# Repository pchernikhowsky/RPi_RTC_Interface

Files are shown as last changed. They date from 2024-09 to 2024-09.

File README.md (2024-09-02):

# Raspberry Pi RTC / Interface Board

## Description

A Raspberry Pi HAT-style interface board that includes:
* [DS3231](https://www.analog.com/en/products/ds3231.html) highly accurate real-time clock (RTC) with replaceable battery backup
* [DS18B20](https://www.analog.com/en/products/ds18b20.html) precision temperature sensor
* 3-pin header terminal for access to the Pi serial console (`/dev/ttyS0` a.k.a. `/dev/serial0`) connection
* Screw terminals for connecting [I2C](https://en.wikipedia.org/wiki/I%C2%B2C) devices (such as displays, sensors, D/A and A/D converters, etc.)
* Screw terminals for connecting [1-Wire](https://en.wikipedia.org/wiki/1-Wire) devices (such as additional DS18B20 sensors and other 1-Wire compatible devices)
<p align="center">
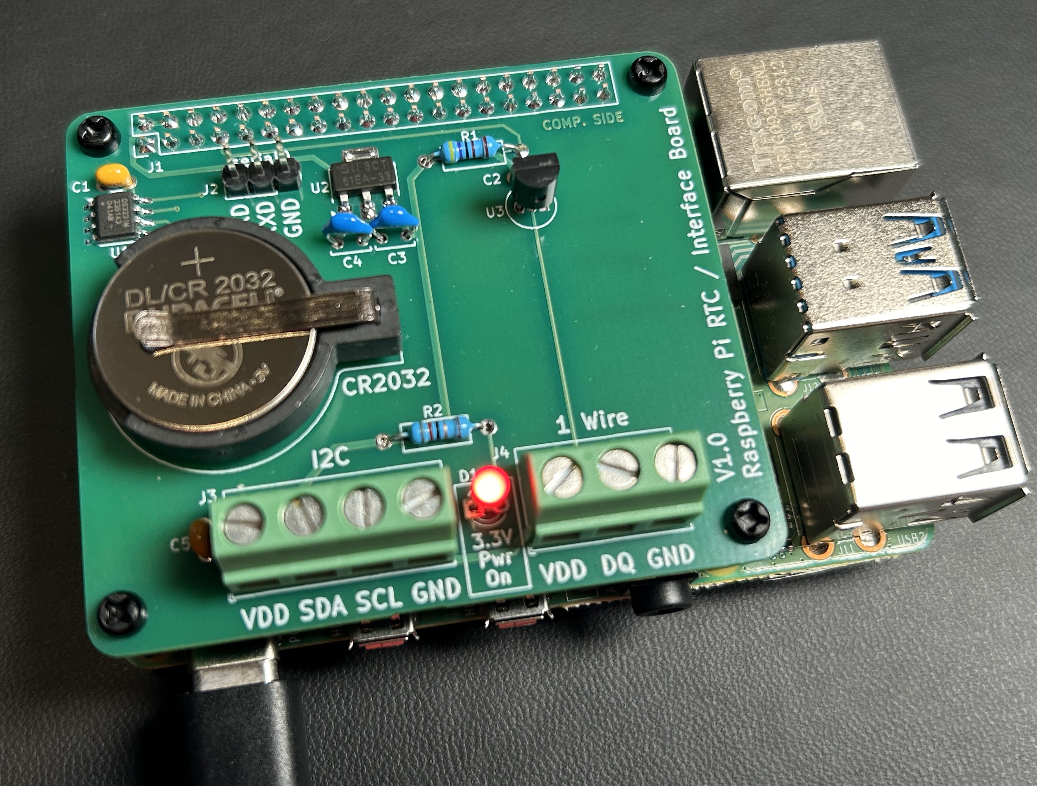
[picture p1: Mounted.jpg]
Completed hardware
  
</p>

## Hardware
### Electrical Interfaces

> [!CAUTION]
> **The Raspberry Pi uses non-5V tolerant 3.3V GPIO**. This includes the `SDA`, `SCL`, and `DQ` signals and the `RXD` and `TXD` serial port pins. Connecting any of these signals to higher voltages may damage your Raspberry Pi.

Two sets of screw terminals are provided:
1. A four-terminal I2C connector with 3.3V power, `SDA`, `SCL`, and ground.
2. A three-terminal 1-Wire connector with 3.3V power, `DQ`, and ground.

Pull-ups for each of the `SDA`, `SCL` and `DQ` signals are provided. An LED indicates that 3.3V power is present at the terminals. 

> [!NOTE]
> As per the spec for the [onboard 5V to 3.3V LDO](https://www.diodes.com/assets/Datasheets/AP7361EA.pdf), the I2C and 1-Wire interfaces are able to supply up to 1 amp of power to connected devices. If the 3.3V power output from the I2C or 1-Wire interfaces is overloaded or shorted to ground (i.e., current draw exceeds 1.5 amps), the LDO regulator will automatically shutdown and the 3.3V power LED will extinguish. Removing the overload/short will automatically restore the 3.3V power supply.

A 3-pin 0.1 in. spacing header connector provides access to the `/dev/ttyS0` serial device signals `RXD`, `TXD` and ground. These are 3.3V logic signals and require external level shifters for compatibility with [RS-232 signal](https://en.wikipedia.org/wiki/RS-232) voltage levels. Many 3.3V to USB interface cables are available for purchase from Amazon, eBay, etc.

> [!NOTE]
> * `RXD` refers to serial data received by (input to) the Pi.
> * `TXD` refers to serial data sent from (output from) the Pi.

### Hardware Construction and Setup

The PCB is designed to mount on any Raspberry Pi Model A+/B+ or later (i.e., any Pi with the 40 pin expansion connecter). While the PCB conforms to the Pi HAT [physical specification](https://github.com/raspberrypi/hats/blob/master/hat-board-mechanical.pdf) there is no EEPROM for full autoconfiguration. As such, this project does not claim 100% compatibility with the Pi HAT specification. 

The schematic and PCB layout were designed using [KiCad 8.0](https://www.kicad.org/). A full hardware design including [schematic](schematic.pdf) and [PCB layout](RPi_RTC_Interface_model.jpg) in KiCad format are provided. If you prefer, the [gerber files](RPi_RTC_interface_gerbers.zip) can be directly uploaded to most PCB manufacturer sites (avoiding the need to install KiCad).

A Microsoft Excel [bill of materials](RPi_RTC_interface_BOM.xlsx) is also included.

> [!TIP]
> I prefer to order my PCBs from [JLCPCB](https://jlcpcb.com/) and components from [DigiKey](https://digikey.com). The total parts cost (excluding the PCB and CR2032 coin cell) is approximately $24 USD (as of September 2024).

Following are unpopulated and populated photos of the front and rear of the PCB.
<p align="center">
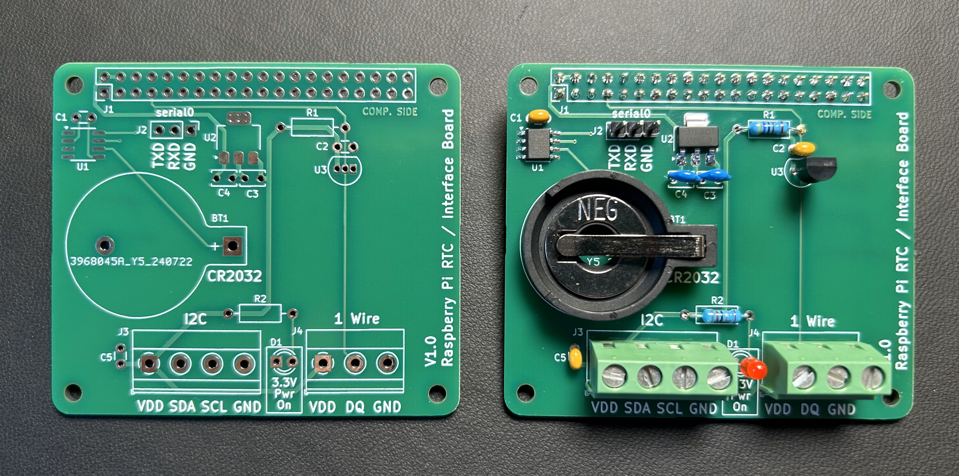
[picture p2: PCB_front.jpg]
PCB front view
  
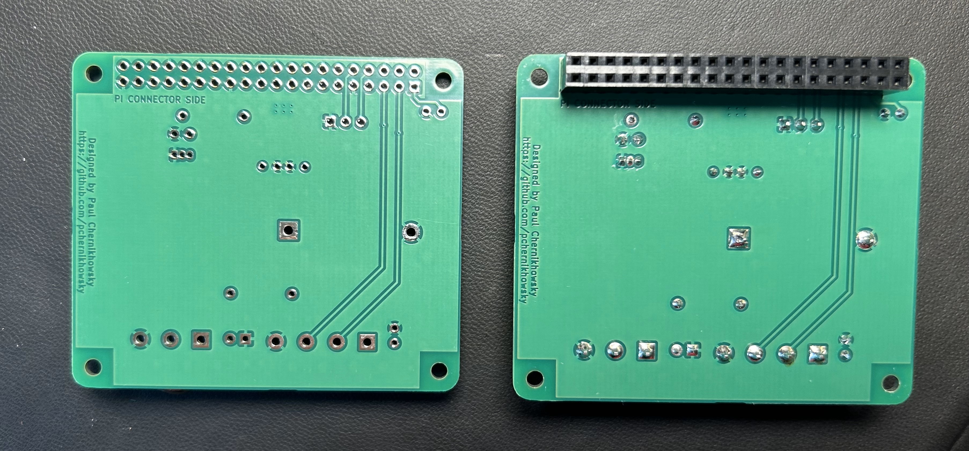
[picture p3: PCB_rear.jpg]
PCB read view
  
</p>

## Updating the Raspberry Pi OS to support the peripherals

1. [Configure the kernel and install the necessary RTC packages.](https://pimylifeup.com/raspberry-pi-rtc/)
2. [Enable the 1-Wire interface.](https://www.circuitbasics.com/raspberry-pi-ds18b20-temperature-sensor-tutorial/)
 
## Version history

* 1.0
    * Initial Release

## License

This project is licensed under the GPL-3.0 License. See the [LICENSE](LICENSE) file for details.

## Acknowledgments

PCB dimensions and layout courtesy:
* [RPi_Hat_Template](https://github.com/devbisme/RPi_Hat_Template)

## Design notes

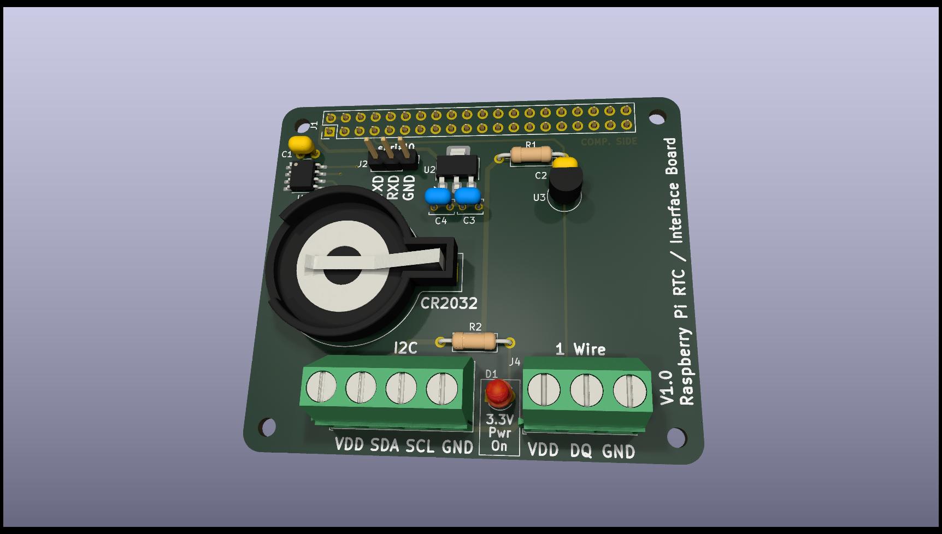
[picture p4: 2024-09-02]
RPi_RTC_Interface_model.jpg

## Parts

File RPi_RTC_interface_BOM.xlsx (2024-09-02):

Reference | Value | Description | Qty | Digikey Part No. | Unit Price | Ext | Digikey Part URL
BT1 | CR2032 3V Li | BATTERY HOLDER COIN 20MM PC PIN | 1 | 36-103-ND | $1.50 | $1.50 | https://www.digikey.ca/en/products/detail/keystone-electronics/103/331620
C1,C2,C3 | 0.1uF | CAP CER 0.1UF 50V X7R RADIAL | 3 | 399-4264-ND | $0.24 | $0.72 | https://www.digikey.ca/en/products/detail/kemet/C320C104K5R5TA/818040
C4,C5 | 2.2uF | CAP CER 2.2UF 25V X5R RADIAL | 2 | 445-181743-ND | $0.22 | $0.44 | https://www.digikey.ca/en/products/detail/tdk-corporation/FG18X5R1E225KRT00/7326659
D1 | LTL-4211N | LED RED DIFFUSED T-1 T/H | 1 | 160-1956-ND | $0.25 | $0.25 | https://www.digikey.ca/en/products/detail/liteon/LTL-4211N/3198521
J1 | PPTC202LFBN-RC | CONN HDR 40POS 0.1 TIN PCB | 1 | S6104-ND | $2.73 | $2.73 | https://www.digikey.ca/en/products/detail/sullins-connector-solutions/PPTC202LFBN-RC/807240
J2 | Phoenix_1729131 | TERM BLK 3P SIDE ENT 5.08MM PCB | 1 | 277-1248-ND | $1.19 | $1.19 | https://www.digikey.ca/en/products/detail/phoenix-contact/1729131/260616
J3 | Phoenix_1729144 | TERM BLK 4P SIDE ENT 5.08MM PCB | 1 | 277-1249-ND | $1.60 | $1.60 | https://www.digikey.ca/en/products/detail/phoenix-contact/1729144/260617
J4 | 1x03 header | CONN HEADER VERT 3POS 2.54MM | 1 | 732-5316-ND | $0.13 | $0.13 | https://www.digikey.ca/en/products/detail/w%C3%BCrth-elektronik/61300311121/4846825
R3 | 4k7 | RES 82 OHM 5% 1/4W AXIAL | 1 | CF14JT4K70CT-ND | $0.10 | $0.10 | https://www.digikey.ca/en/products/detail/stackpole-electronics-inc/CF14JT4K70/1741428
R6 | 82R | RES 82 OHM 5% 1/4W AXIAL | 1 | CF14JT82R0CT-ND | $0.10 | $0.10 | https://www.digikey.ca/en/products/detail/stackpole-electronics-inc/CF14JT82R0/1741513
U1 | DS18B20 | SENSOR DIGITAL -55C-125C TO92 | 1 | 5272-DS18B20-EV-ND | $3.69 | $3.69 | https://www.digikey.ca/en/products/detail/evvo/DS18B20-EV/22482011
U2 | AP7361EA-33E-13 | LDO CMOS HICURR SOT223 | 1 | 31-AP7361EA-33E-13CT-ND | $0.45 | $0.45 | https://www.digikey.ca/en/products/detail/diodes-incorporated/AP7361EA-33E-13/16186483
U3 | DS3231MZ+ | IC RTC CLK/CALENDAR I2C 8SOIC | 1 | 175-DS3231MZ+TRLCT-ND | $11.08 | $11.08 | https://www.digikey.ca/en/products/detail/analog-devices-inc-maxim-integrated/DS3231MZ-TRL/2754408
 |  |  |  |  | Total USD (before taxes and shipping): | $23.98

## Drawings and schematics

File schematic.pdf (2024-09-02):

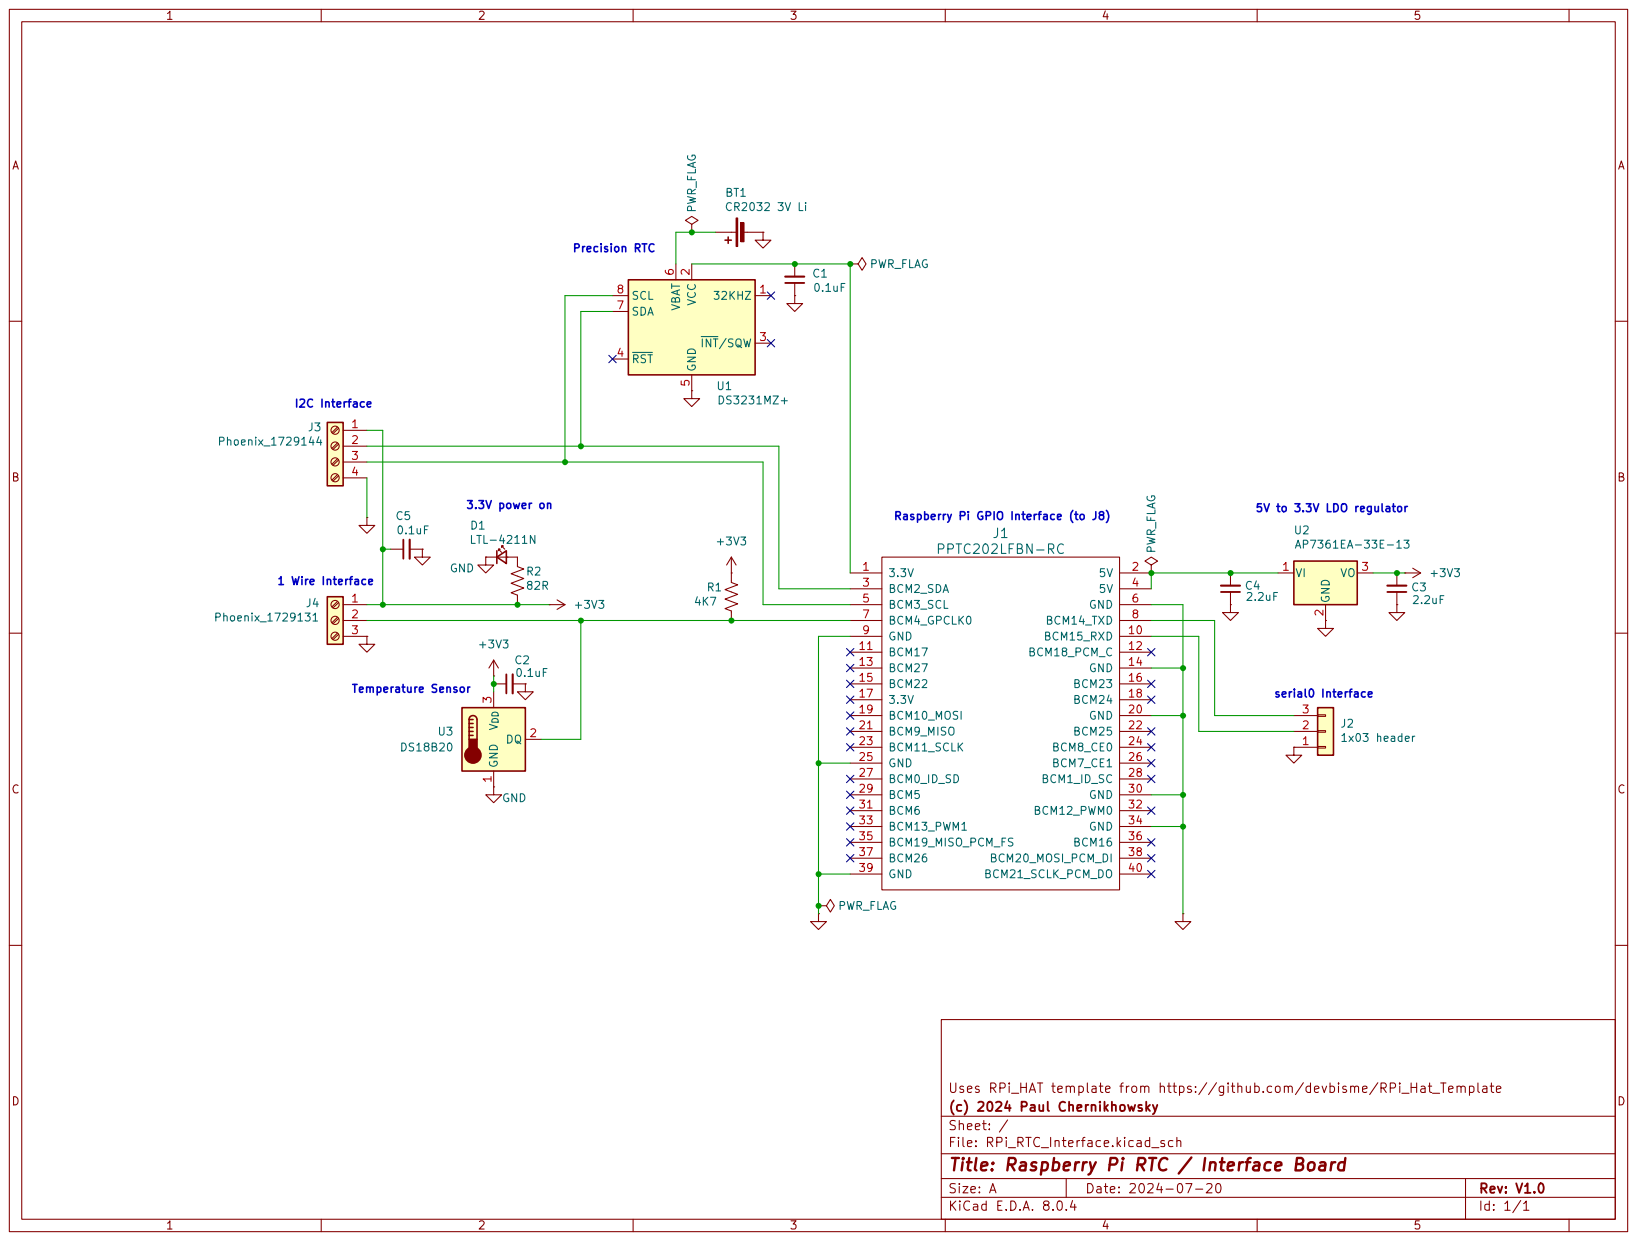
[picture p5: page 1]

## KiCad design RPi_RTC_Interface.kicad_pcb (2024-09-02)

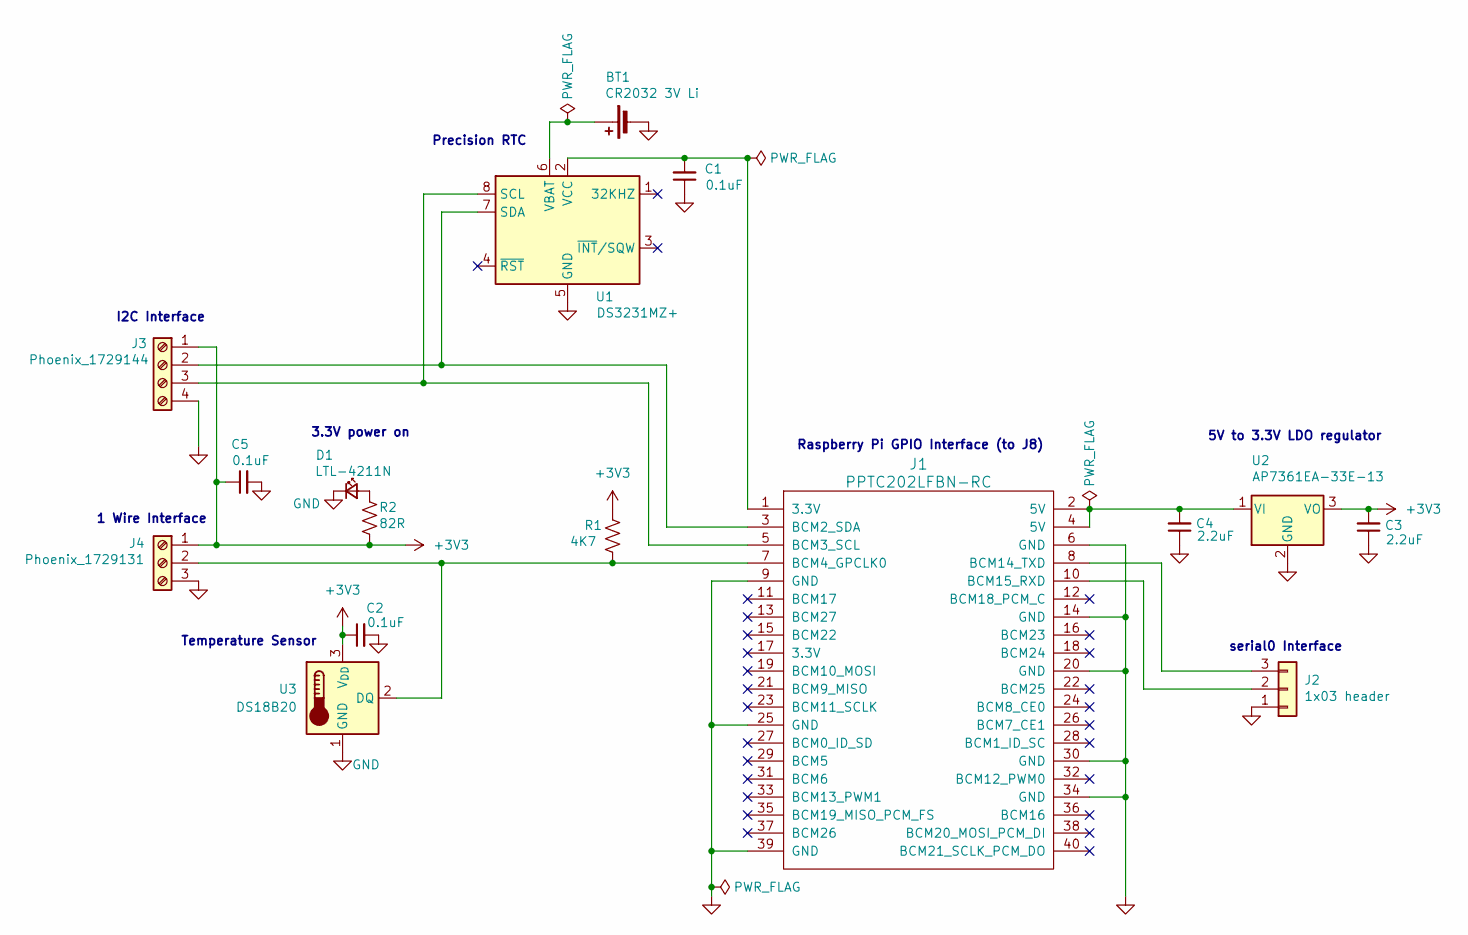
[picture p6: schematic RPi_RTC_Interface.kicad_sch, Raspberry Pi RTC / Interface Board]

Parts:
BT1: CR2032 3V Li; BatteryHolder_Keystone_103_1x20mm
C1, C2, C5: 0.1uF; C_Disc_D3.0mm_W1.6mm_P2.50mm
C3, C4: 2.2uF; CAPRB250W50L400T250H550
D1: LTL-4211N; LED_D3.0mm
J1: PPTC202LFBN-RC; RPI_PinSocket_2x20
J2: 1x03 header; PinHeader_1x03_P2.54mm_Vertical
J3: Phoenix_1729144; TerminalBlock_Phoenix_MKDS-1,5-4-5.08_1x04_P5.08mm_Horizont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
J4: Phoenix_1729131; TerminalBlock_Phoenix_MKDS-1,5-3-5.08_1x03_P5.08mm_Horizont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
R1: 4K7; R_Axial_DIN0207_L6.3mm_D2.5mm_P10.16mm_Horizontal
R2: 82R; R_Axial_DIN0207_L6.3mm_D2.5mm_P10.16mm_Horizontal
U1: DS3231MZ+; SOIC-8_3.9x4.9mm_P1.27mm
U2: AP7361EA-33E-13; SOT-223-3_TabPin2
U3: DS18B20; TO-92_Inline

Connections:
+3V3: C2.1, C3.2, C5.1, J3.1, J4.1, R1.1, R2.2, U2.3 (VO), U3.3 (V_{DD})
GND: BT1.2 (-), C1.1, C2.2, C3.1, C4.1, C5.2, D1.1 (K), J1.6 (GND), J1.9 (GND), J1.14 (GND), J1.20 (GND), J1.25 (GND), J1.30 (GND), J1.34 (GND), J1.39 (GND), J2.1, J3.4, J4.3, U1.5 (GND), U2.2 (GND), U3.1 (GND)
unnamed: BT1.1 (+), U1.6 (VBAT)
unnamed: D1.2 (A), R2.1
unnamed: J1.3 (BCM2_SDA), J3.2, U1.7 (SDA)
unnamed: J1.5 (BCM3_SCL), J3.3, U1.8 (SCL)
unnamed: J1.7 (BCM4_GPCLK0), J4.2, R1.2, U3.2 (DQ)
unnamed: J1.8 (BCM14_TXD), J2.3
unnamed: J1.10 (BCM15_RXD), J2.2
unnamed: C1.2, J1.1 (3.3V), U1.2 (VCC)
unnamed: C4.2, J1.2 (5V), J1.4 (5V), U2.1 (VI)

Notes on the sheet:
1 Wire Interface
I2C Interface
3.3V power on
5V to 3.3V LDO regulator
Precision RTC
serial0 Interface
Raspberry Pi GPIO Interface (to J8)
Temperature Sensor

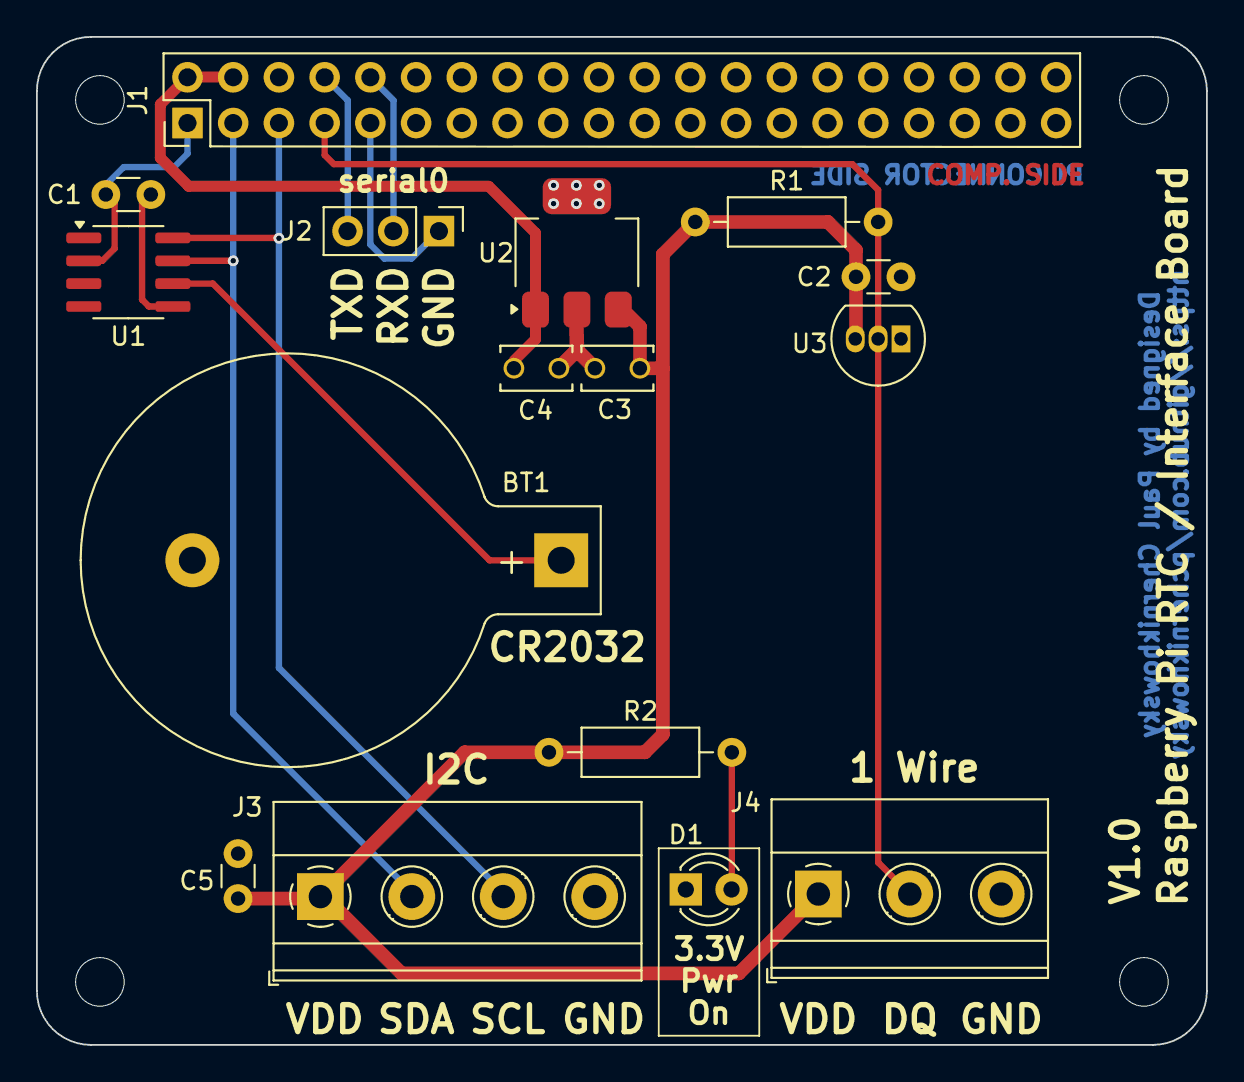
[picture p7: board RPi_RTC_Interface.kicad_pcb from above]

Board: 2 copper layers, 65.0 x 56.0 mm, 20 parts (0 on the bottom side), 11 nets.

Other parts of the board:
REF1, REF2, REF3, REF4: MountingHole_2.7mm

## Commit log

2024-09-02 remove gerbers/*
    [RPi_RTC_Interface-B_Cu.gbl, RPi_RTC_Interface-B_Mask.gbs, RPi_RTC_Interface-B_Paste.gbp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]
2024-09-02 Added schematic PDF
2024-09-02 Added PCB photos
2024-09-02 Added KiCad 3D model image
2024-09-02 Update BOM and gerbers.zip
    [RPi_RTC_interface_BOM.xlsx]
2024-09-02 Remove old BOM
    [RPi RTC interface BOM.xlsx]
2024-09-02 Updated gerbers

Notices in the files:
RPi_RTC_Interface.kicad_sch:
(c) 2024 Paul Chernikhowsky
